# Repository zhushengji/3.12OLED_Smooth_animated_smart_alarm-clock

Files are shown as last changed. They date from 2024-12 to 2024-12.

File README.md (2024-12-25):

# 3.12OLED_Smooth_animated_smart_alarm-clock

## 一款基于esp32实现的丝滑动画小闹钟

视频：https://youtu.be/SYInRoCkLO8

视频：https://www.bilibili.com/video/BV1hukBYzEhU/?spm_id_from=333.1387.homepage.video_card.click

## 静石键位及功能说明：

1.顶上四个键是键1，键2，键3，键4，正面是左键，右键；

2.键1键2是选择键，键3是确定，键4是返回；

3.唤醒后长按键4可以进入主菜单；

4.唤醒后左键可进入计时器，再次点击可暂停计时，键4退出；

5.唤醒后右键可进入番茄钟，5秒内左键加1分钟，右键加5分钟，5秒内无操作则进入番茄计时

6.查看实时天气或自动校准时间时需要联网，此时设备会自动连接上次连过的网络，失败后会进入自动配网；

7.自动配网下会自动扫描周围2.4G网络，扫描成功后屏幕会提醒，此时用手机等设备搜索并连接“静石配网wifi”即可进入配网，选择wifi名并填入对应的密码即可完成配网。第三栏的心知天气秘钥是获取天气的，建议自己免费申请一个并填入以获取最优的体验，如果没有可以不填；

## 项目介绍

本项目是基于ESP32和3.12寸OLED实现的桌面时钟。

此时此刻已实现丝滑翻页、实时天气动画、震动唤醒、温湿度检测、闹钟、OTA、亮度调节、自动校准、手动校准、离线天气预测，番茄钟。后续将持续完善更新。

本作品灵感源于白橙大佬的效果图，但我实现的不好。后续外观多数要升级，目前先发一个给大家玩玩。

本作品名为“静石”。林深藏古寺，老树掩荒碑。能长期与时间作伴的，大概只有静静的顽石吧！希望静石能给各位在忙碌的间隙提供一丝宁静！

## 项目参数
核心器件：

SSD1362驱动的3.12寸OLED，分辨率256\*64

MPU6050

bmp280

AHT20

RTX8025

顶键\*4

面板按键\*2(尺寸选择6\*6*4.3）

蜂鸣器

注意事项

本作品不含烧录电路，需要烧录器或烧录夹实现烧录，请悉知！

电池尺寸为802095

面板厚度1.0，主板厚度0.8

交流群：855540712 进群请回答问题，群里更新进度最快

## 特别说明：

**使用代码自行点3.12寸OLED发生乱码现象的小伙伴需要把u8g2库里的u8x8_d_ssd1362.c的第488行，第374行，还有301行，U8X8_CA(0xa0, 0xc3)改成U8X8_CA(0xa0, 0xc1)即可**

a0bb3fac4f7ee4f2527682af89fc310
9d6d8b7dc297bdcc11b59f055cea049

## 如果你喜欢本作品且余粮比较多，可以请作者喝杯冰阔落，谢谢！

48a73fccaab32dd9f51743931c423e1

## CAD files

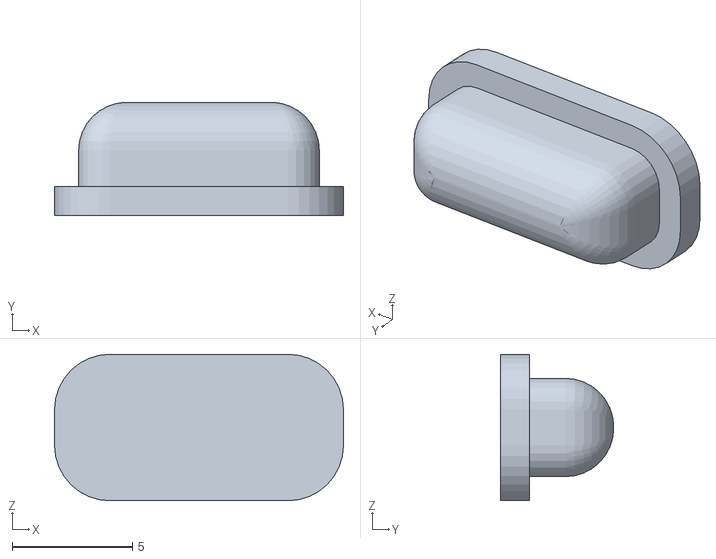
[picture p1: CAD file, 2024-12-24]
静石按钮.stl
12.0 x 4.70 x 6.08

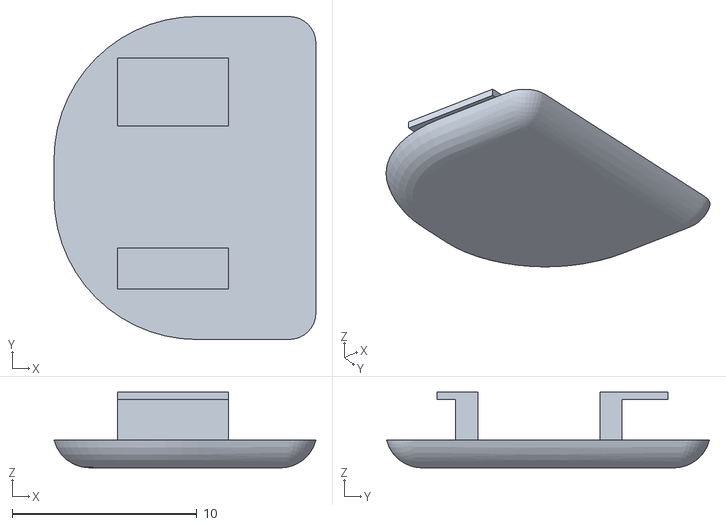
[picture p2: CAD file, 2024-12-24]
按钮右.stl
14.2 x 17.5 x 4.10

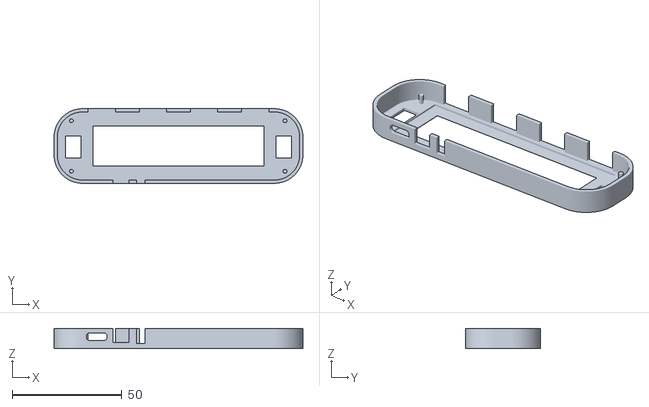
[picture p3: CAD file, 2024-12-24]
静石内壳.stl
113.4 x 34.0 x 9.20

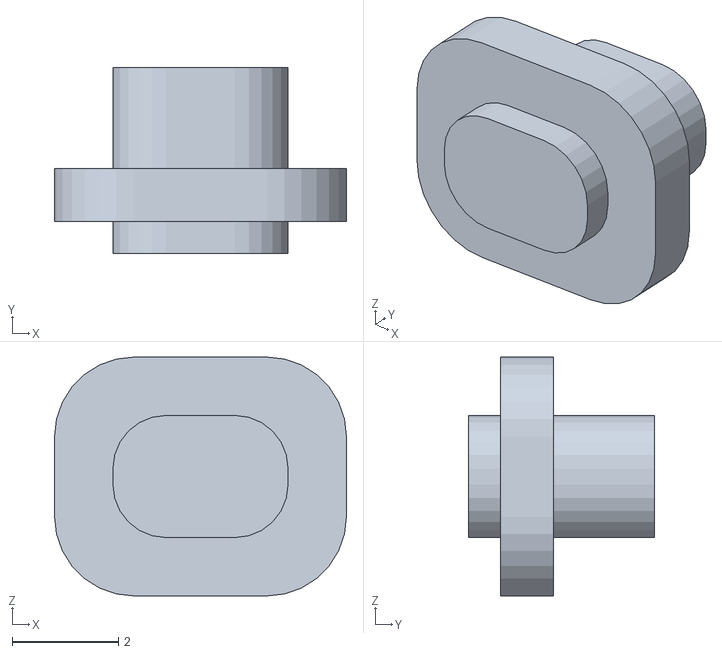
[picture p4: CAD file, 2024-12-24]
静石复位键.stl
5.50 x 3.50 x 4.50

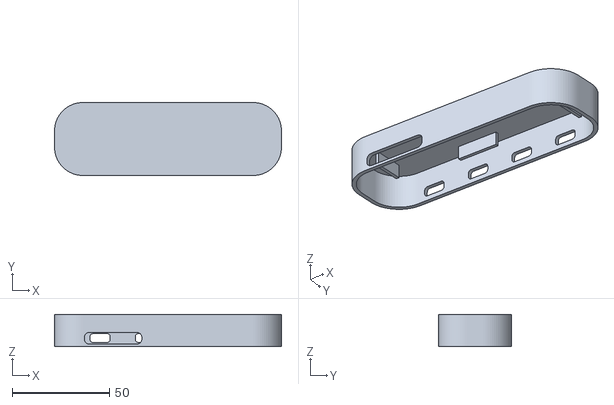
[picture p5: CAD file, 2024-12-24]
静石测试外壳.stl
117.0 x 37.6 x 16.5

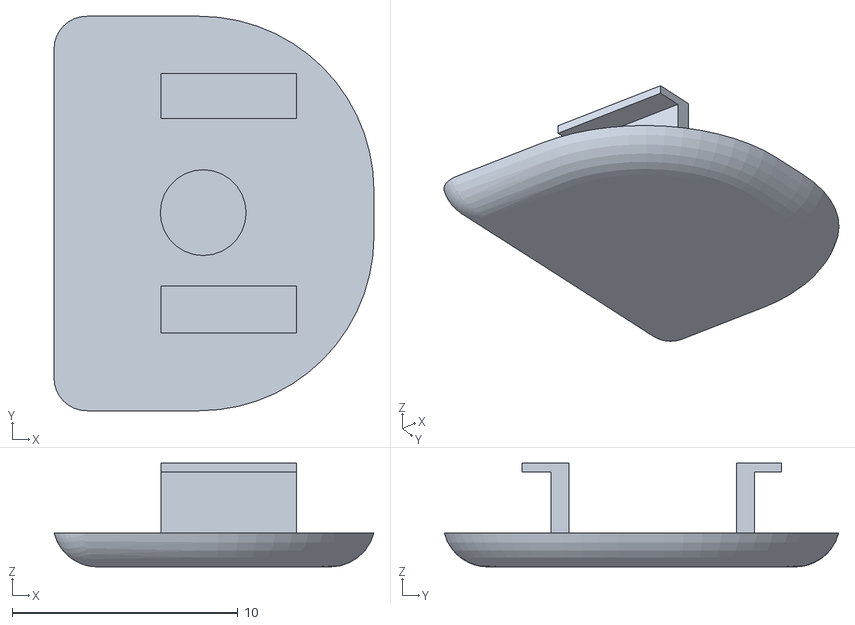
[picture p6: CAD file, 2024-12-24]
按钮左.stl
14.2 x 17.5 x 4.60

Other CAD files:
静石外壳.stl

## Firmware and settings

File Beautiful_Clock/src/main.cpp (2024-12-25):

#include <Arduino.h>
#include <math.h>
#include <EEPROM.h>
#include "nvs.h"
#include "nvs_flash.h"
#include <U8g2lib.h>
#include <WiFi.h>
#include <WiFiClient.h>
#include <WiFiAP.h>
#include <WebSocketsServer.h>
#include <AsyncTCP.h>
#include <ESPAsyncWebServer.h>
#include <AsyncElegantOTA.h>
#include "ESPmDNS.h"
#include <HTTPClient.h>
#include <ArduinoJson.h>
#include <Wire.h>
#include <SPI.h>
#include <AHT20.h>
#include <RTC_RX8025T.h>
#include <TimeLib.h>
#include "gb2312.c"
#include "driver/rtc_io.h"
#include "esp_sleep.h"
// LIS3DH I2C 地址
#define LIS3DH_ADDR 0x18
// #include <FastLED.h>
RTC_DATA_ATTR float arr[16];
RTC_DATA_ATTR float voltage;
#include "BMP280Code.h"
#include "bmp.h"
// Adafruit_BMP280 bmp;
// #define LED_PIN 33
// #define NUM_LEDS 4
// #define BRIGHTNESS 180
// #define LED_TYPE WS2812
// #define COLOR_ORDER GRB
// CRGB leds[NUM_LEDS];
const char *ntpServer = "cn.pool.ntp.org";
const long gmtOffset_sec = 8 * 60 * 60;
const int daylightOffset_sec = 3600;
String daysOfTheWeek[] = {"-", "星期天", "星期一", "星期二", "星期三", "星期四", "星期五", "星期六"};
String monthsNames[] = {"-", "01", "02", "03", "04", "05", "06", "07", "08", "09", "10", "11", "12"};
struct Alarm_obj
{
  short a_hour;
  short a_min;
  short a_frequency;
} Alarm;
short sleepTime = 120; // 单位：秒
String oweathers = "";
void writeRegister(uint8_t reg, uint8_t value);
void configureLIS3DHInterrupt();
void remindAnimate();
void pomodoroSet();
void stopwatchStart();
void pomodoroAnimate();
void stopwatchAnimate();
bool getNetTime();
void ManualsetRTC();
void cliptimeRun();
void disMenu();
void setsleeptime();
void Alarm_ring();
extern const uint8_t dinkie_9[52247] U8G2_FONT_SECTION("dinkie_9");
#define key4 23
#define key3 22
#define key2 21
#define key1 0
#define keyleft 14
#define keyright 34
#define BUZZ 32
// #define WSLED 33
#define BAT 12
AHT20 aht20;
tmElements_t RXtm;
// 闹钟是否打开标记位
bool alarmState = false;
// 离线天气开关
// bool offlineweatherState = false;
//唤醒方式
bool wakeFlagState = false;
struct tm timeinfo;
AsyncWebServer server(80);
U8G2_SSD1362_256X64_F_4W_HW_SPI u8g2(U8G2_R2, /* cs=*/4, /* dc=*/16, /* reset=*/17);
short temperature, humidity;
// 公开或私有标记
bool isSale = true;
String XZcode = "SxzwEXUQLKZoS1-nv";
#include "pic.h"
#include "MenuCode.h"
#include "Webservice.h"
#include "NTP_RTC.h"
#include "getData.h"
#include "wakeCode.h"
#include "alarmCode.h"
#include "displayUI.h"
#include "PomodoroClock.h"
void setup()
{
  /**
   * eeprom位置说明
   * 1：存储亮度
   * 5: 存储休眠时长
   * 2：存储闹钟小时数据
   * 3：存储闹钟分钟数据
   * 4：存储闹钟频次数据
   * 5：存储离线时钟/天气时钟种类
   * 6:存储离线天气开关
   * 7.唤醒方式
   */
  Serial.begin(115200);

  EEPROM.begin(64);
  Wire.begin(25, 26);
  Alarm.a_hour = EEPROM.read(2);
  Alarm.a_min = EEPROM.read(3);
  Alarm.a_frequency = (short)EEPROM.read(4);
  Serial.printf("闹钟小时：%d,闹钟分钟：%d,闹钟频率：%d\n", Alarm.a_hour, Alarm.a_min, Alarm.a_frequency);

  if (EEPROM.read(5) != 255)
  {
    sleepTime = EEPROM.read(5) * 60;
  }
  if (EEPROM.read(7) == 1)
  {
    wakeFlagState = true;
  }
  // if (EEPROM.read(6) == 1)
  // {
  //   offlineweatherState = true;
  //   pinMode(GPIO_NUM_35, LOW);
  //   esp_sleep_enable_ext0_wakeup(GPIO_NUM_35, 1);
  //   attachInterrupt(digitalPinToInterrupt(GPIO_NUM_35), gpio_isr_handler, FALLING);
  // }
  Serial.printf("休眠时长：%d\n", sleepTime);
  bmp.begin();
  init280();
  aht20.begin();
  RTC_RX8025T.init();
  u8g2.begin();
  u8g2.setContrast(EEPROM.read(1));
  Serial.printf("屏幕亮度：%d\n", EEPROM.read(1));
  u8g2.enableUTF8Print(); // 开启UTF8字符功能

  pinMode(key4, INPUT_PULLUP);
  pinMode(key3, INPUT_PULLUP);
  pinMode(key2, INPUT_PULLUP);
  pinMode(key1, INPUT_PULLUP);
  pinMode(keyleft, INPUT_PULLUP);
  pinMode(keyright, INPUT_PULLUP);
  // remindAnimate();
  // return;

  pinMode(BUZZ, OUTPUT);
  pinMode(BAT, INPUT);

  // 判断什么原因启动的
  print_wakeup_reason();
  // 公开或私有标记
  if (isSale)
  {
    int num = random(0, 10);
    u8g2.clearBuffer();
    u8g2.drawXBMP(0, 0, 256, 64, shengming);
    u8g2.sendBuffer();
    if (num % 3 == 0)
    {
      while (digitalRead(key1) != LOW && digitalRead(key2) != LOW && digitalRead(key3) != LOW && digitalRead(key4) != LOW)
      {
        delay(100);
      }
    }
  }
  // configureMPU(1);
   configureLIS3DHInterrupt();
  disMenu();
}

void loop()
{
}
// 设置中断处理函数
// void IRAM_ATTR gpio_isr_handler()
// {
//   u8g2.setDrawColor(1);
//   remindAnimate();
//   cliptimeRun();
// }

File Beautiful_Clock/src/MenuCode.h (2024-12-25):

void menu_bg_static(short li_order[], String set_str, String des_str, short *box_len);
/**
 * @brief
 * 绘制时针函数
 * @param x0 起始x
 * @param y0 起始y
 * @param len 时针长度
 * @param t 具体时间（时）
 */
void drawHline(int16_t x0, int16_t y0, int16_t len, float t)
{
    float b = 0;   // 三角形的底
    float a = 0;   // 三角形的高
    int16_t angle; // 偏转角度
    int fx = 0, fy = 0;
    if (t > 12)
        t -= 12;
    if (t == 3)
    {
        b = len;
    }
    else if (t == 12 || t == 0)
    {
        a = -1 * len;
    }
    else if (t == 9)
    {
        b = 0 - len;
    }
    else if (t == 6)
    {
        a = len;
    }
    else if (t < 3)
    {
        angle = 90 - t * 30;
        a = len * sin(angle * 3.15159 / 180);
        b = len * cos(angle * 3.15159 / 180);
        a = -1 * a;
    }
    else if (t > 3 && t < 6)
    {
        angle = 90 - (t - 3) * 30;
        b = len * sin(angle * 3.15159 / 180);
        a = len * cos(angle * 3.15159 / 180);
    }
    else if (t > 6 && t < 9)
    {
        angle = 90 - (t - 6) * 30;
        a = len * sin(angle * 3.15159 / 180);
        b = len * cos(angle * 3.15159 / 180);
        b = -1 * b;
    }
    else if (t > 9)
    {
        angle = 90 - (t - 9) * 30;
        b = len * sin(angle * 3.15159 / 180);
        a = len * cos(angle * 3.15159 / 180);
        a = -1 * a;
        b = -1 * b;
    }

    fx = x0 + b; // 目标x坐标
    fy = y0 + a; // 目标y坐标
    u8g2.drawLine(x0, y0, fx, fy);
    // display.drawLine(x0,y0,fx,fy,heise);
    // display.nextPage();
    // Serial.print("测试时间 时:  ");Serial.print(t);Serial.print("   x:  ");Serial.print(fx);Serial.print("   y:  ");Serial.println(fy);
}
/**
 * @brief
 * 绘制分针函数
 * @param x0 起始x
 * @param y0 起始y
 * @param len 分针长度
 * @param t 具体时间（分）
 */
void drawMline(int16_t x0, int16_t y0, int16_t len, int16_t t)
{
    float b = 0;   // 三角形的底
    float a = 0;   // 三角形的高
    int16_t angle; // 偏转角度
    int fx = 0, fy = 0;
    if (t == 15)
    {
        b = len;
    }
    else if (t == 0)
    {
        a = -1 * len;
    }
    else if (t == 45)
    {
        b = -1 * len;
    }
    else if (t == 30)
    {
        a = len;
    }
    else if (t < 15)
    {
        angle = 90 - t * 6;
        a = len * sin(angle * 3.15159 / 180);
        b = len * cos(angle * 3.15159 / 180);
        a = -1 * a;
    }
    else if (t > 15 && t < 30)
    {
        angle = 90 - (t - 15) * 6;
        b = len * sin(angle * 3.15159 / 180);
        a = len * cos(angle * 3.15159 / 180);
    }
    else if (t > 30 && t < 45)
    {
        angle = 90 - (t - 30) * 6;
        a = len * sin(angle * 3.15159 / 180);
        b = len * cos(angle * 3.15159 / 180);
        b = -1 * b;
    }
    else if (t > 45)
    {
        angle = 90 - (t - 45) * 6;
        b = len * sin(angle * 3.15159 / 180);
        a = len * cos(angle * 3.15159 / 180);
        a = -1 * a;
        b = -1 * b;
    }

    fx = x0 + b; // 目标x坐标
    fy = y0 + a; // 目标y坐标
    u8g2.drawLine(x0, y0, fx, fy);
    // display.drawLine(x0,y0,fx,fy,heise);
}
/**
 * @brief 横向或纵向移动，只能是一维的
 * @param y 当前y或x坐标或待变化的长度
 * @param fy 目标y或x坐标或目标长度
 * @param step 移动幅度
 * @param slow_cnt 修正幅度
 */
bool ui_siglerun(short *y, short *fy, uint8_t step, uint8_t slow_cnt)
{

    uint8_t temp;
    temp = abs(*fy - *y) > slow_cnt ? step : 1;
    if (*y < *fy)
    {
        *y += temp;
    }
    else if (*y > *fy)
    {
        *y -= temp;
    }
    else
    {
        return true;
    }
    return false;
}
#define DAMPING_FACTOR 0.85    // 阻尼系数，控制回弹效果0.85
#define POSITION_THRESHOLD 2   // 位置阈值
#define VELOCITY_THRESHOLD 0.2 // 速度阈值

/**
 * @brief 带回弹的动画坐标计算函数
 * @param y 要变化的数据
 * @param fy 目标数据
 * @param velocity 速度记录
 * @param step 速度
 * @return
 */
bool ui_bounce(short *y, short *fy, float *velocity, float step)
{
    // if(abs(*y)-abs(*fy)<=POSITION_THRESHOLD){
    //     return false;
    // }
    // 计算加速度
    float acceleration = (*fy - *y) * step;

    // 更新速度
    *velocity = *velocity * DAMPING_FACTOR + acceleration;

    // 更新位置
    *y += (short)*velocity;

    // 检查是否到达目标位置并且速度足够小
    if (fabs(*fy - *y) < POSITION_THRESHOLD && fabs(*velocity) < VELOCITY_THRESHOLD)
    {
        *y = *fy;      // 将位置修正到最终目标位置
        *velocity = 0; // 将速度重置为0
        return false;
    }

    return true;
}
/**
 * @param x 当前x坐标
 * @param fx 目标x坐标
 * @param y 当前y坐标
 * @param fy 目标y坐标
 * @param stepx x移动幅度
 * @param stepy y移动幅度
 * @param slow_cnt 修正幅度
 */
bool ui_run_plane(short *x, short *fx, short *y, short *fy, uint8_t stepx, uint8_t stepy, uint8_t slow_cnt)
{
    uint8_t tempX, tempY;

    // 计算 X 轴的步幅
    tempX = abs(*fx - *x) > slow_cnt ? stepx : 1;
    if (*x < *fx)
    {
        *x += tempX;
    }
    else if (*x > *fx)
    {
        *x -= tempX;
    }

    // 计算 Y 轴的步幅
    tempY = abs(*fy - *y) > slow_cnt ? stepy : 1;
    if (*y < *fy)
    {
        *y += tempY;
    }
    else if (*y > *fy)
    {
        *y -= tempY;
    }

    // 判断是否仍需移动
    if (*x == *fx && *y == *fy)
    {
        return false; // 移动完成
    }
    return true; // 继续移动
}
const unsigned char *nli[10] = {ling, yi, er, san, si, wu, liu, qi, ba, jiu};
short hsc = 0;
short hgc = 0;
short msc = 0;
short mgc = 0;
/**
 * @brief 更新时间4个数位上的数字
 * @param hourx 小时数据
 * @param minitx 分钟数据
 * @param nhs 小时数据的十位
 * @param nhg 小时数据的各位
 * @param nms 分钟数据的十位
 * @param nmg 分钟数据的个位
 */
void prepairClip(short hourx, short minitx, short *nhs, short *nhg, short *nms, short *nmg)
{
    *nhs = hourx / 10;
    *nhg = hourx % 10;
    *nms = minitx / 10;
    *nmg = minitx % 10;
}
/**
 * @brief 翻页时钟消失动画
 */
void drawTimedisapper()
{
    String weekstr = daysOfTheWeek[RXtm.Wday];
    String datestr = String(tmYearToCalendar(RXtm.Year)) + "-" + monthsNames[RXtm.Month] + "-" + String(RXtm.Day);
    u8g2.setDrawColor(1);
    u8g2.setFont(dinkie_9);
    u8g2.setCursor(32 - (weekstr.length() * 4 / 2), 20);
    u8g2.print(weekstr);
    u8g2.setFont(u8g2_font_tinytim_tr);
    u8g2.setCursor(26 - (datestr.length() * 5 / 2), 10);
    u8g2.print(datestr);
    u8g2.drawXBMP(5, 23, 12, 12, wendu);
    u8g2.setCursor(18, 32);
    u8g2.print(temperature);
    u8g2.print("'C");
    u8g2.drawXBMP(5, 36, 12, 12, shidu);
    u8g2.setCursor(18, 46);
    u8g2.print(humidity);
    u8g2.print("%");
    u8g2.drawXBMP(5, 49, 12, 12, kongqi);
    u8g2.setCursor(18, 57);
    u8g2.print("Good");
    u8g2.drawXBMP(62, 3, 38, 54, nli[hsc]);
    u8g2.drawXBMP(98, 3, 38, 54, nli[hgc]);
    u8g2.drawXBMP(158, 3, 38, 54, nli[msc]);
    u8g2.drawXBMP(198, 3, 38, 54, nli[mgc]);
    u8g2.drawRFrame(54, 2, 95, 58, 5);
    u8g2.drawRFrame(151, 2, 95, 58, 5);
    u8g2.setDrawColor(0);
    u8g2.drawBox(0, 0, 255, 2);
    u8g2.drawBox(0, 60, 255, 4);
}
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

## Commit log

2024-12-24 README.md
    项目介绍与预览
2024-12-24 静石外壳打印文件
    [按钮右.stl, 按钮左.stl, 静石内壳.stl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]
2024-12-24 免费固件
    功能描述见readme
2024-12-24 静石PCB文件
    立创EDA标准版打开
2024-12-24 静石原理图
2024-12-25 项目源码
    [custom_partitions.csv]
